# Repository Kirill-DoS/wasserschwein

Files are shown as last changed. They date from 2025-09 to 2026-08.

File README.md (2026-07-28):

# Wasserschwein — робот для физического «Арканоида»

Wasserschwein — это система, в которой камера сверху видит мяч и каретку
робота, а компьютер отправляет каретке команды движения. Raspberry Pi Pico
принимает эти команды по Bluetooth и управляет мотором. Цель — подвезти каретку
к месту, где мяч пересечёт её линию.

Это не обязательный проект с нейросетью: в обычной работе программа выделяет
мяч и метку робота по цвету. Это проще, быстрее и легче проверять. Нейросеть
YOLO оставлена только как отдельный эксперимент.

## Начните отсюда

Полное пошаговое руководство — от установки программ до проверки настоящего
робота — находится в [docs/PROJECT_GUIDE_RU.md](docs/PROJECT_GUIDE_RU.md).
Оно написано для человека, который не обязан знать ни машинное обучение, ни
фильтр Калмана.

Краткая безопасная последовательность для компьютерной части:

```bash
git clone https://github.com/Kirill-DoS/wasserschwein.git
cd wasserschwein
cp .env.example .env
python3 -m venv .venv
source .venv/bin/activate
python3 -m pip install -r requirements.txt
python3 -m unittest discover -s tests -v
```

Затем заполните `.env`, подключите камеру и Bluetooth-модуль, проведите
разметку поля и запустите:

```bash
python3 -m vision.main
```

## Самое важное о настройках

Все изменяемые настройки находятся в одном файле `.env` в корне репозитория:

- камера и Bluetooth;
- размеры поля и цветовые диапазоны;
- скорость и плавность движения каретки;
- параметры прошивки Pico, включая пины и таймер безопасности.

Файл `.env` не попадает в Git, потому что содержит настройки конкретного
стенда. В репозитории хранится только безопасный шаблон
[.env.example](.env.example). Не меняйте значения пинов и ESC, пока не
проверите схему и не прочитаете соответствующий раздел подробного руководства.

## Структура

```text
vision/        Компьютерное зрение, прогноз мяча и управление роботом
firmware/      Прошивка Raspberry Pi Pico и сборка файла .uf2
hardware/      Модели деталей и конструкторские материалы
tools/         Отдельные диагностические и учебные утилиты
tests/         Автоматические проверки без камеры и робота
docs/          Подробное руководство и правила поля
```

## Частые команды

| Задача | Команда из корня репозитория |
| --- | --- |
| Установить зависимости | `python3 -m pip install -r requirements.txt` |
| Запустить автоматические тесты | `python3 -m unittest discover -s tests -v` |
| Найти номер камеры | `python3 tools/camera_index.py` |
| Ручной стоп робота | `python3 -m vision.bluetooth_cli S` |
| Запустить игру | `python3 -m vision.main` |
| Собрать прошивку Pico | `make -C firmware all` |

## Безопасность

- Первые тесты выполняйте с поднятыми колёсами либо на минимальной мощности.
- Держите кнопку остановки и отключение питания в пределах руки.
- Закрытие программы, потеря мяча или метки робота отправляют команду `S`.
- Pico самостоятельно останавливает каретку, если новые команды не приходят
  дольше времени `PICO_COMMAND_TIMEOUT_MS` из `.env`.

Подробный порядок проверки и диагностики неисправностей — в
[руководстве](docs/PROJECT_GUIDE_RU.md).

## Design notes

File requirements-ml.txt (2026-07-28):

# Необязательные зависимости для экспериментов с YOLO, не нужны для управления роботом.
-r requirements.txt
ultralytics>=8.3
torch>=2.1
torchvision>=0.16
PyYAML>=6.0

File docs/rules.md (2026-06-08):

Полигон (см. рис. 1) представляет собой поле квадратной формы, ограниченное жестко
закрепленными бортами. Полигон имеет симметричную поперечную выпуклость в
центре. С противоположных сторон полигона установлены рейки для перемещения
роботов.
Характеристики полигона:
длина – 1500 мм;
ширина – 1500 мм;
высота бортов – не менее 100 мм;
толщина стенок – не менее 10 мм;
высота выпуклости – 35+/-10 мм;
форма продольного сечения выпуклости – равномерная криволинейная, с
плавным переходом к основанию полигона, опционально параболическая,
эллиптическая;
цвет полигона – белый;
Рейка представляет собой профиль квадратного сечения, жестко закрепленный на продольных бортах полигона

Характеристики рейки:
продольных бортах полигона.
Характеристики рейки:
размер сечения – квадрат со стороной 20 мм;
высота над полигоном – 100 мм;
расстояние до борта полигона – 100 мм;
материал – металл;
Характеристики мяча (опционально покрашенный мяч для гольфа):
цвет мяча – красный, оранжевый или розовый;
диаметр мяча – 43 мм;
масса мяча – 46

Веб-камеры:
размещение – на балку, смонтированную по продольной оси поля, на высоте
2000+/-200 мм;
направление обзора – вертикально вниз;
подключение – через USB порт к компьютеру участника.

4.2. Ход матча
Матч состоит из двух таймов.
Каждый тайм длится 3 минуты или пока разница в счете в тайме не достигнет 7 баллов.
В финальных матчах олимпийской системы длительность тайма составляет 5 минут.
Между таймами предусмотрен перерыв 3 минуты. По соглашению команд время
перерыва может быть уменьшено.
В начале тайма мяч вводится в игру от центра полигона в сторону определенную
жеребьевкой, параллельно боковым бортам. Каждый последующий ввод мяча
производится аналогично в направлении, противоположном направлению
предыдущего ввода мяча.
Гол засчитывается роботу, если мяч оказался полностью за рейкой противоположного
борта.
Потеря мяча происходит в случае, если мяч остановился так, что роботы не могут
произвести удар в сторону соперника.
Мяч вводится в игру после каждого гола, потери или нарушения.

5. Нарушения и дисквалификация
Нарушения, наказуемые присуждением 1 балла сопернику:
робот касается мяча дольше 2 секунд подряд
произошла потеря мяча на своей половине поля или мяч не выбит на сторону
соперника в течении 10 секунд после касания мяча роботом
Нарушения, наказуемые дисквалификацией робота в тайме:
участник коснулся полигона, робота или управляющий компьютер во время
матча без разрешения судьи
робот по техническим причинам (отказ моторов, разряд батареи, поломка
ударного механизма, переворот робота, отсутствие реакции робота на
перемещение мяча и пр.) или по усмотрению оператора не может
продолжать матч, в том числе, если не может перекинуть мяч на сторону
соперника
В случае дисквалификации робота соперника присуждаются дополнительные баллы в
количестве необходимом для досрочного завершения тайма с разницей 7 баллов в
пользу соперника

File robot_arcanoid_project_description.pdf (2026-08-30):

КЛУБ ТЕХНИЧЕСКОГО ТВОРЧЕСТВА «PINMODE»

## ОПИСАНИЕ ИННОВАЦИОННОГО ПРОЕКТА

«Разработка робота-арканоида для настольного тенниса»

Автор проекта:
Член клуба «PinMode»
Ломашко Данила Сергеевич

Минск, 2026

3. Введение (Постановка задачи) | 3
3.1. Актуальность исследования | 3
3.2. Цель и задачи проекта | 3
3.3. Гипотеза исследования | 3
4. Основная часть | 4
4.1. Архитектура и компонентная база аппаратного комплекса | 4
4.2. Конструктивное исполнение и кинематика передачи | 4
4.3. Выявленные инженерные проблемы и оптимизация конструкции | 5
5. Заключение | 6
5.1. Краткие выводы | 6
5.2. Практическая значимость | 6
5.3. Направления дальнейшего развития | 6
6. Список использованных источников | 7
7. Приложения | 7

### 2. ОГЛАВЛЕНИЕ

### 3. ВВЕДЕНИЕ (ПОСТАНОВКА ЗАДАЧИ)

### 3.1. Актуальность исследования

Проектирование специализированных робототехнических систем для динамических спортивных игр (в частности, настольного тенниса) требует решения жестких инженерных противоречий: обеспечения высокой скорости перемещения исполнительных органов при сохранении малого веса, высокой прочности и жесткости конструкции. Автоматизация процесса отбивания мяча сопряжена с необходимостью компенсации динамических нагрузок, возникающих при работе высокооборотистых бесколлекторных двигателей и резком изменении вектора движения. Разработка доступного, высокоскоростного робота-арканоида на базе современных микроконтроллерных платформ и аддитивных технологий является актуальной задачей в области прикладной мехатроники и робототехники.

### 3.2. Цель и задачи проекта

Цель работы: Разработка, сборка и отладка действующего прототипа робота-арканоида для настольного тенниса, способного позиционировать ударный механизм (пушер) и осуществлять отбивание мяча на высоких скоростях вращения импеллера без потери кинематической точности и устойчивости платформы.

Задачи проекта:

Спроектировать и изготовить несущую платформу робота на основе листовых полимерных материалов (ПВХ) и компонентов, изготовленных методом 3D-печати.
Разработать печатную плату системы управления и интегрировать аппаратный стек на базе микроконтроллера Raspberry Pi RP2040 Zero, мостовых драйверов TA6586, регуляторов скорости ESC и бесколлекторных моторов (BLDC).
Спроектировать и реализовать зубчато-ременную передачу с коэффициентом редукции 3:1 на базе профиля GT2 для привода пушера.
Исследовать и устранить динамические дефекты конструкции: опрокидывающий момент при разгоне/торможении и гироскопические прецессионные биения импеллера на частотах свыше 4000 об/мин.

### 3.3. Гипотеза исследования

Предполагается, что применение двухопорного двустороннего узла фиксации оси импеллера в сочетании с тефлоновыми (PTFE) опорами скольжения с низким коэффициентом трения позволит полностью устранить эффект «восьмерки» при оборотах BLDC-двигателя выше 4000 об/мин и стабилизировать пространственное положение робота без существенных механических потерь на трение.

### 4. ОСНОВНАЯ ЧАСТЬ

### 4.1. Архитектура и компонентная база аппаратного комплекса

Аппаратная схема робота-арканоида построена по модульному принципу с разделением силовых и управляющих цепей. В основе вычислительного ядра лежит микроконтроллер RP2040

1.

2.

3.

4.

Zero (двухядерный ARM Cortex-M0+, 133 МГц). Питание электроники осуществляется через импульсные понижающие DC-DC стабилизаторы, обеспечивающие помехозащищенность логической части от бросков напряжения силовых приводов.

Специально для данного проекта была спроектирована и изготовлена односторонняя печатная плата (PCB). На плате размещена обвязка центрального контроллера, включая интегральный двухканальный H-мостовой драйвер TA6586 для управления моторами позиционирования, светодиодные индикаторы статуса и пользовательские кнопки ввода команд.

Компонент | Характеристики / Модель | Назначение в системе
Микроконтроллер | RP2040 Zero (ARM Cortex-M0+) | Генерация ШИМ, обработка алгоритмов движения
Силовые приводы привода | 2х Коллекторных мотора Pololu 20 мм | Линейное перемещение платформы робота
Драйвер двигателей | TA6586 (DIP/SOP-8) | Управление коллекторными моторами Pololu
Привод пушера (отбивалки) | 2х BLDC 2200KV + 2х ESC 40A | Вращение импеллера ударного механизма
Плата управления | Односторонняя PCB собственного изготовления | Маршрутизация сигналов, обвязка МК и индикации

### 4.2. Конструктивное исполнение и кинематика передачи

Несущее шасси робота имеет габаритные размеры 250×120×5 мм и выполнено из высокопрочной ПВХ-плиты. Для защиты внутренних компонентов и жесткости конструкции по периметру установлены защитные боковые бортики. Передача крутящего момента от силовых бесколлекторных двигателей BLDC к валам пушера реализована посредством ременной передачи стандарта GT2. Кинематический расчет передачи выполнен исходя из коэффициента понижения скорости i = 3:1:

i = z₂ / z₁ = 3 / 1

где z₁ — количество зубьев ведущей шестерни на валу BLDC, z₂ — количество зубьев ведомой шестерни импеллера. Данное соотношение гарантирует передачу требуемого крутящего момента при сохранении высокого диапазона рабочих оборотов.

В процессе проектирования широко применялись аддитивные технологии (FDM-печать). На 3D-принтере износостойкими пластиками были изготовлены следующие оригинальные детали:

Корпусные держатели и кронштейны для тефлоновых элементов;
Мотомауты (крепления) для коллекторных и бесколлекторных двигателей;
Зубчатые шкивы и шестерни профиля GT2;
Переходные втулки для адаптации 3-мм валов BLDC-моторов; Стабилизационные кожухи для бесколлекторных двигателей.

•
•
•
•
•

### 4.3. Выявленные инженерные проблемы и оптимизация конструкции

В ходе натурных испытаний начальной версии прототипа были выявлены два существенных технических дефекта, влияющих на точность и надежность работы:

Проблема 1: Продольная неустойчивость платформы (заваливание вперед/назад). При резком изменении направления движения линейных приводов Pololu возникал опросный момент, заваливающий платформу.
Решение: В нижнюю часть шасси были интегрированы 4 опорных элемента из политетрафторэтилена (PTFE, тефлон), контактирующие с алюминиевым направляющим треком. За счет чрезвычайно низкого коэффициента трения тефлона по алюминию (μ ≈ 0.04) проблема заваливания платформы была полностью решена без увеличения паразитного механического сопротивления и потери мощности моторов.

Проблема 2: Динамический биение импеллера («восьмерка») на высоких оборотах. При росте частоты вращения BLDC-моторов свыше 4000 об/мин в импеллере (ударном блоке) возникали резонансные явления и гироскопический прецессионный момент. Поскольку первоначальная конструкция предусматривала консольное крепление вала импеллера только с верхней стороны, консоль испытывала изгибные деформации, что приводило к ходу детали «восьмеркой» и быстрому износу ремня GT2.

Решение (Текущий этап модернизации): В настоящее время осуществляется проектирование интегрированного силового силового узла (модульного моноблока). В новой ревизии вал импеллера фиксируется по схеме «двухопорная балка» — с оппозитным расположением подшипников сверху и снизу. Кроме того, в данный модуль заложены посадочные места для моторов и механизм точной регулировки натяжения ремня GT2 с помощью пазовых направляющих, что полностью ликвидирует несоосность и люфты.

### 5. ЗАКЛЮЧЕНИЕ

### 5.1. Краткие выводы

В ходе выполнения проекта был спроектирован, собран и проверен действующий прототип робота-арканоида для игры в настольный теннис. Натурные испытания подтвердили правильность выбранного кинематического соотношения ременной передачи (3:1) и
эффективность | применения | тефлоновых | слайдеров | для | стабилизации | корпуса.
Разрабатываемый модернизированный двухопорный узел крепления импеллера решает проблему пространственных вибраций на частотах более 4000 об/мин.

### 5.2. Практическая значимость

Разработая платформа демонстрирует высокий потенциал применения в качестве тренировочного оборудования для настольного тенниса, специализированных робототехнических аттракционов, а также в качестве учебного стенда в учреждениях образования для демонстрации
систем | управления | BLDC-двигателями, | динамической | балансировки | и | разработки
высокоскоростных приводов.

### 5.3. Направления дальнейшего развития

Завершение изготавливаемой конструкции двухопорного силового модуля импеллера и его интеграция в шасси;

•

Внедрение оптической системы технического зрения (на базе камеры) для автоматического отслеживания траектории теннисного мяча;
Разработка закрытого корпуса для улучшения аэродинамики и безопасности при работе на максимальных оборотах привода.

### 6. СПИСОК ИСПОЛЬЗОВАННЫХ ИСТОЧНИКОВ

Autodesk Inc. Autodesk Fusion 360: Integrated CAD/CAM/CAE Software [Электронный ресурс]. — 2026. — Режим доступа: https://www.autodesk.com/products/fusion-360
FreeCAD Community. FreeCAD: An open-source parametric 3D modeler [Электронный ресурс]. — 2026. — Режим доступа: https://www.freecad.org
Raspberry Pi Ltd. RP2040 Datasheet: High-performance microcontroller with flexible digital interfaces. — 2021. — 638 p.
Краузе М. Справочник по конструкционным пластмассам и фторопластам (PTFE/Тефлон). — Л.: Химия, 1988. — 224 с.

### 7. ПРИЛОЖЕНИЯ

Приложение А. Фотографические материалы действующего прототипа робота-арканоида (ракурсы: вид сверху, вид снизу, вид спереди).

•

•

1.

2.

3.

4.

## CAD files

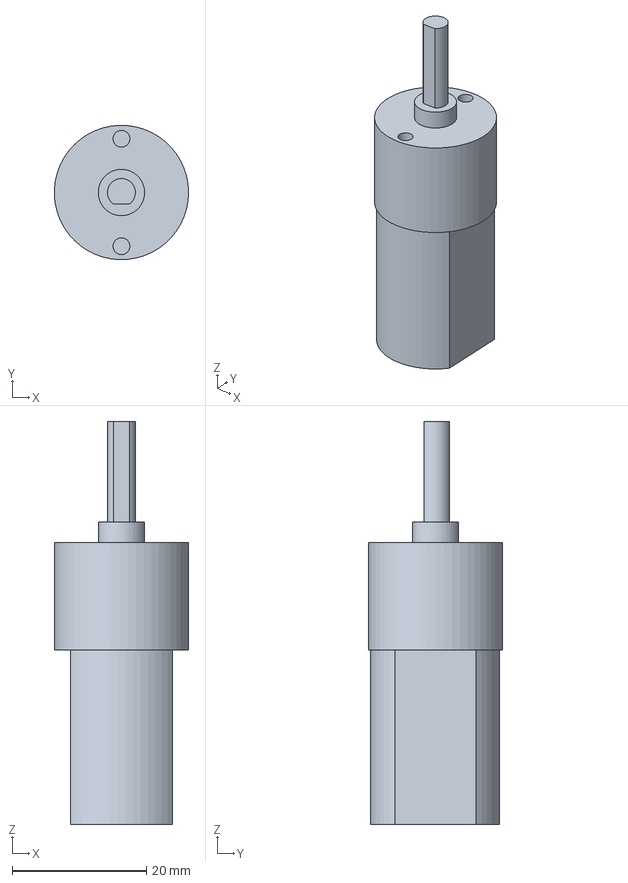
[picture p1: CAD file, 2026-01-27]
hardware/cad/3D_components/motor.FCStd
20.0 x 20.0 x 60.0 mm

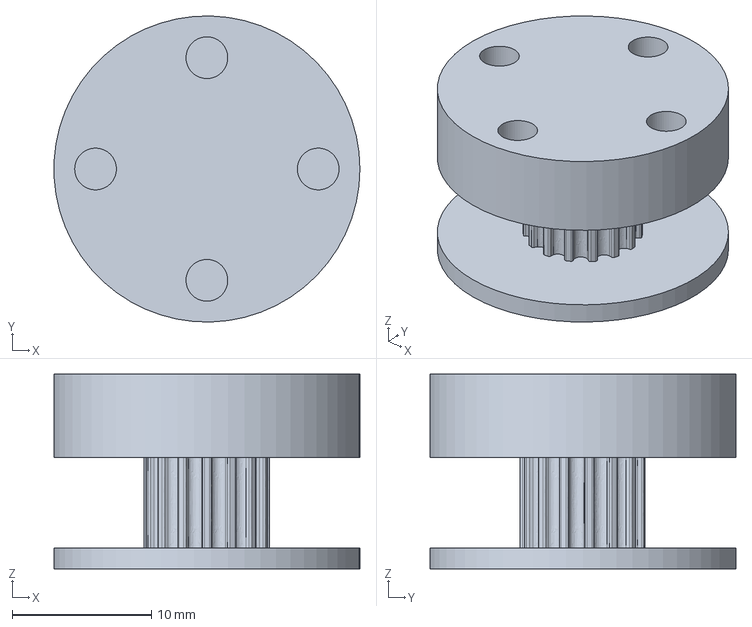
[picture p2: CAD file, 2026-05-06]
hardware/cad/NewPusherSys/BLCDGear.FCStd
22.0 x 22.0 x 14.0 mm

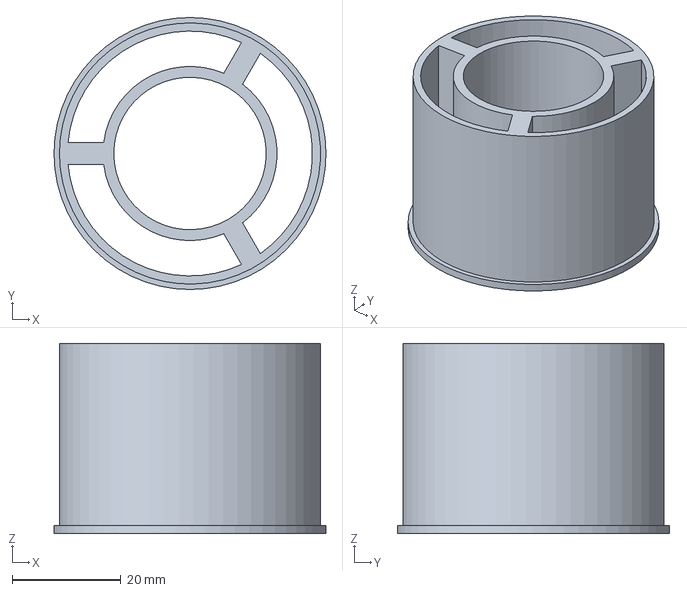
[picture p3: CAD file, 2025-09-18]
hardware/construction/Weel_pusher.FCStd
50.0 x 50.0 x 35.0 mm

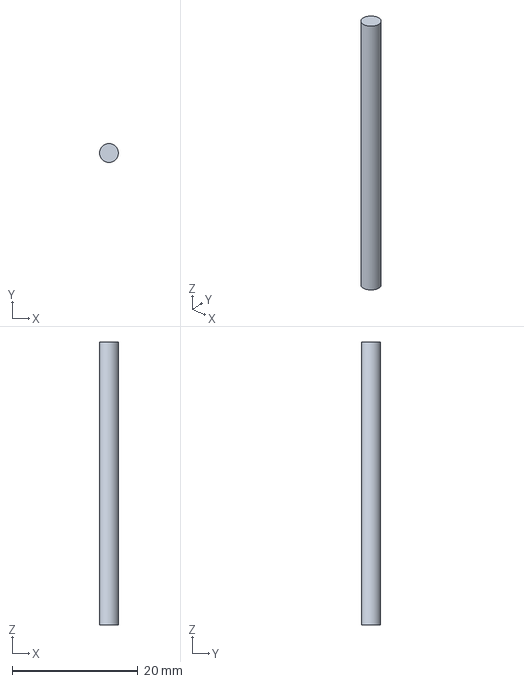
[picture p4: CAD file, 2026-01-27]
hardware/cad/3D_components/shaft.FCStd
3.00 x 3.00 x 45.0 mm

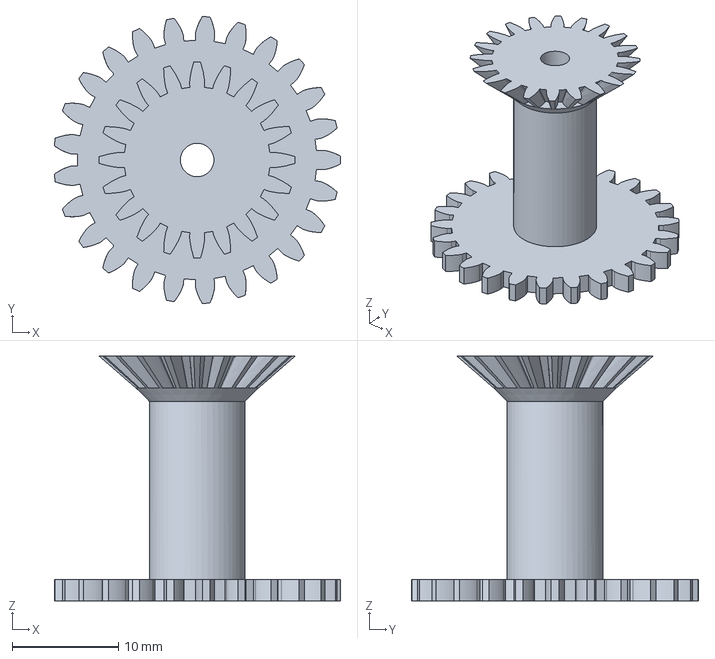
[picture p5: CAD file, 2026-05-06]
hardware/cad/involute_gear_1.FCStd
26.9 x 27.0 x 23.0 mm

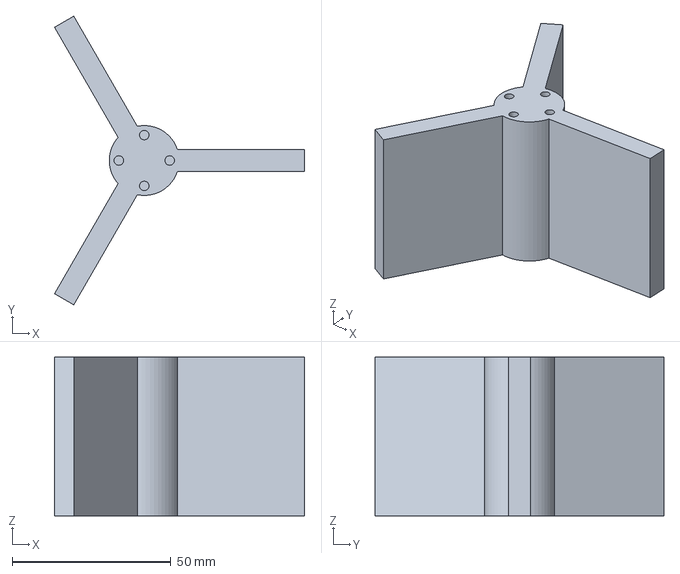
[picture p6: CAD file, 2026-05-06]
hardware/cad/NewPusherSys/pusher.FCStd
78.7 x 90.8 x 50.0 mm

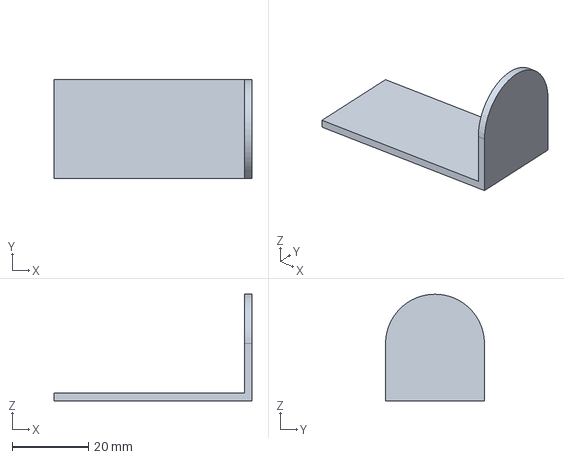
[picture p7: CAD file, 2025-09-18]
hardware/construction/arcanoid_cart.FCStd
52.0 x 26.0 x 28.0 mm

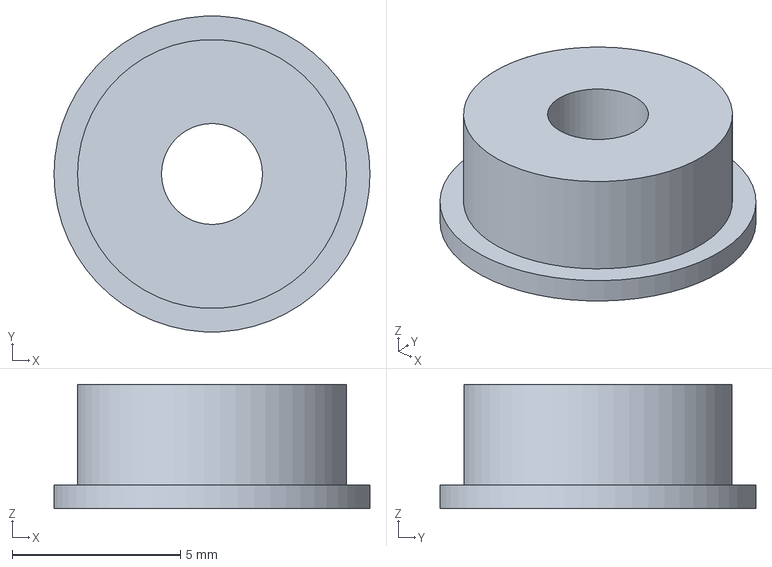
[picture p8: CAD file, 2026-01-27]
hardware/cad/3D_components/bearing.FCStd
9.40 x 9.39 x 3.70 mm

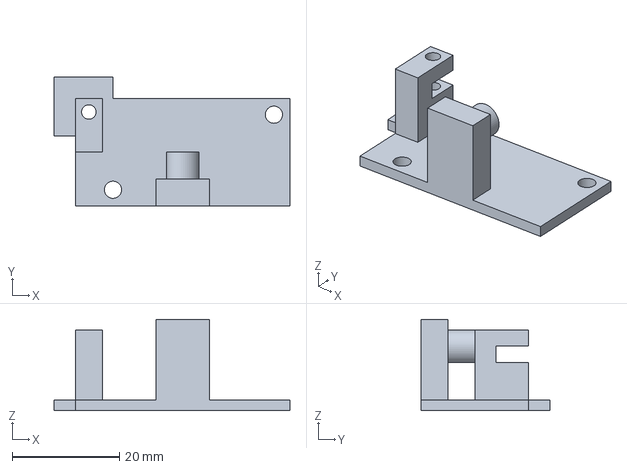
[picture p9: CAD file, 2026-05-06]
hardware/cad/NewPusherSys/BeltTightening.FCStd
44.0 x 24.0 x 17.0 mm

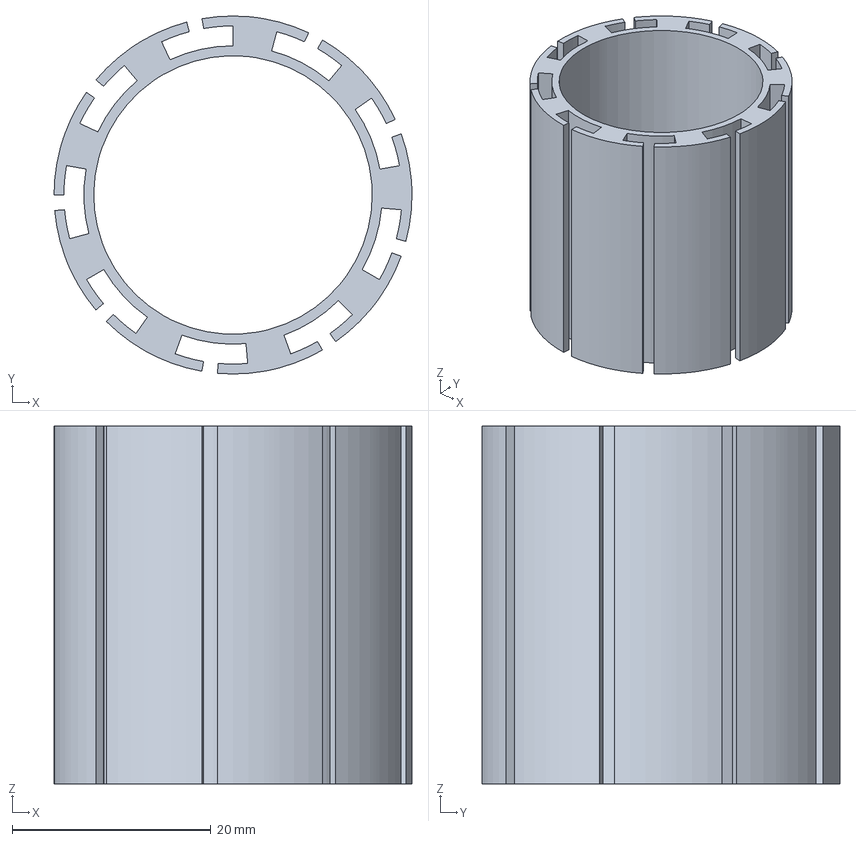
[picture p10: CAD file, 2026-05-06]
hardware/cad/weel_pusher_new.FCStd
36.0 x 36.0 x 36.0 mm

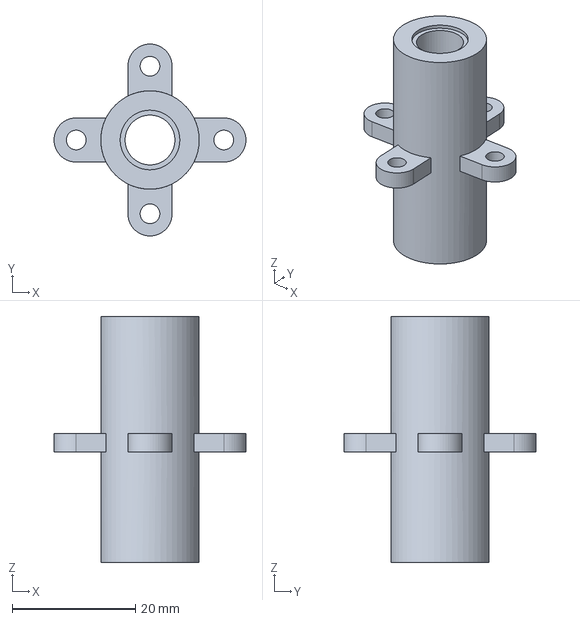
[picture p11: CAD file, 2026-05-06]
hardware/cad/NewPusherSys/Sleeve.FCStd
31.2 x 31.2 x 40.0 mm

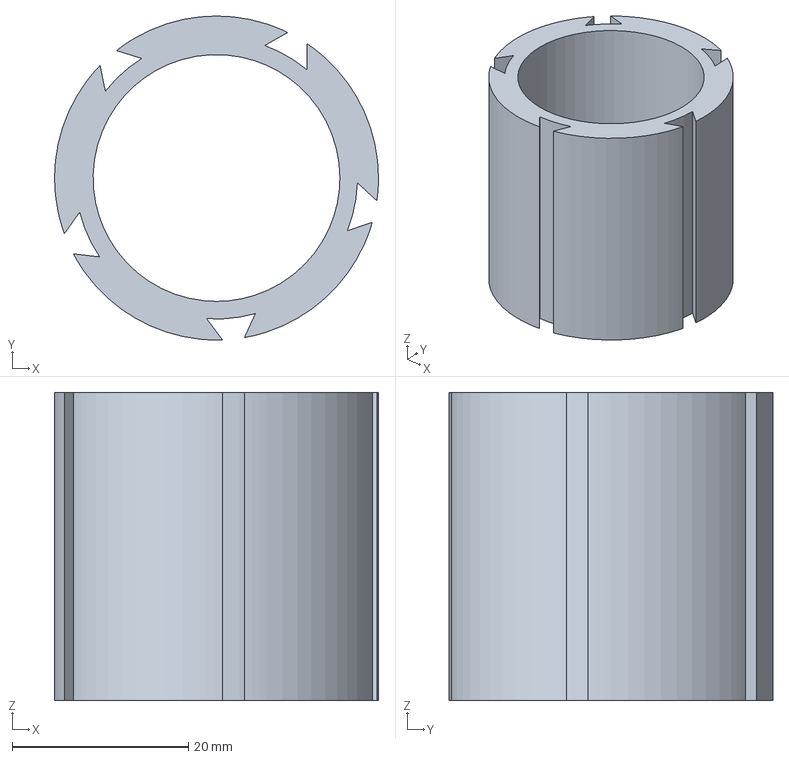
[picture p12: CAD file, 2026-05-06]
hardware/cad/weel_pusher.FCStd
36.8 x 36.8 x 35.0 mm

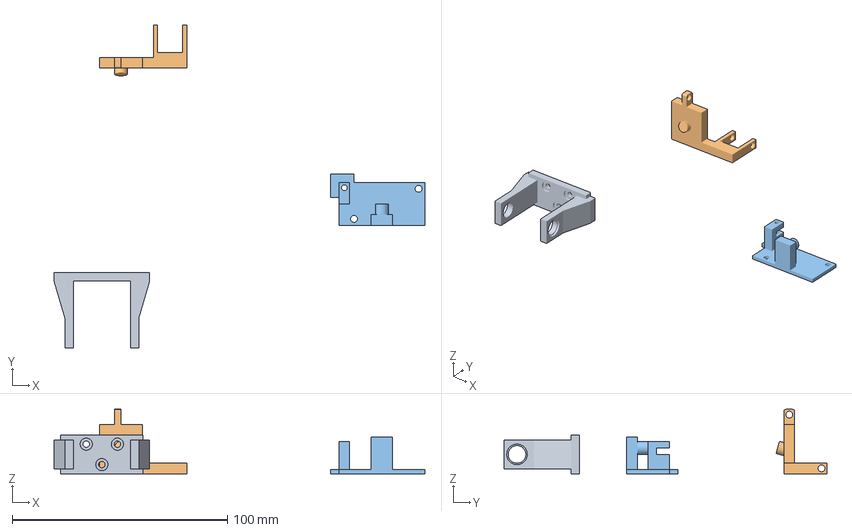
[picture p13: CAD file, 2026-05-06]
hardware/cad/NewPusherSys/weel_kiper.3mf
172.5 x 150.1 x 30.0 mm

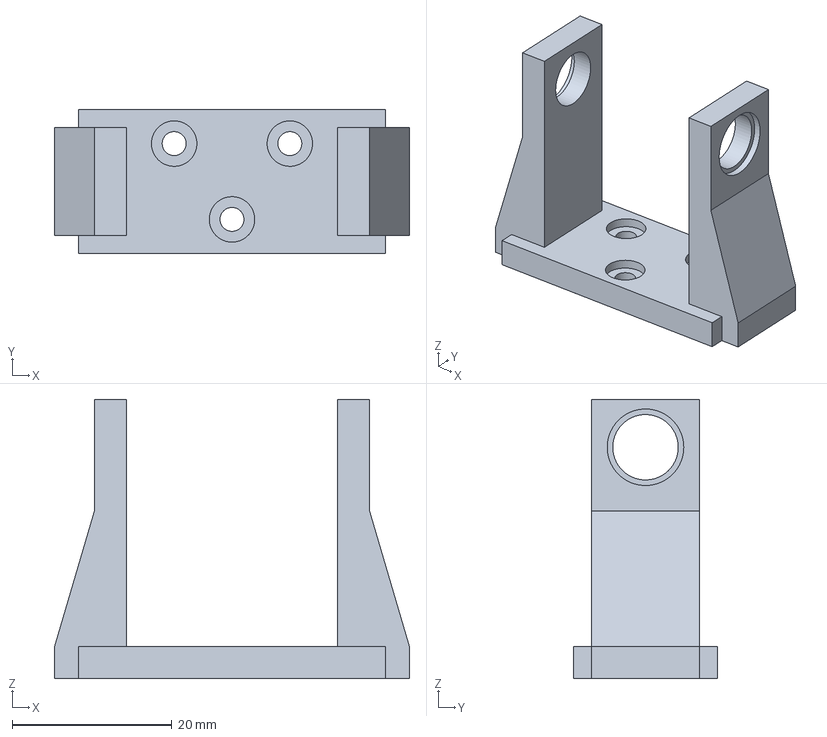
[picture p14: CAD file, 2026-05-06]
hardware/cad/weel_kiper.FCStd
44.5 x 18.0 x 35.0 mm

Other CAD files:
hardware/cad/assembly_pusher.FCStd
hardware/cad/assembly_robot.FCStd
hardware/cad/back_form_pusher.FCStd
hardware/cad/NewPusherSys/ArmTightening.FCStd
hardware/cad/BLCD_kipper.FCStd
hardware/cad/NewPusherSys/ArmTightening.3mf
hardware/cad/NewPusherSys/BLCDGear.3mf
hardware/cad/NewPusherSys/BeltTightening.3mf
hardware/cad/NewPusherSys/BigGear.3mf
hardware/cad/NewPusherSys/BigGear.FCStd
hardware/cad/NewPusherSys/CurtainDrive.FCStd
hardware/cad/NewPusherSys/Sleeve.3mf
hardware/cad/NewPusherSys/WeelTightening.3mf
hardware/cad/NewPusherSys/WeelTightening.FCStd
hardware/cad/NewPusherSys/pusher.3mf
hardware/cad/arcanoid1.3mf.FCStd
hardware/cad/arcanoid_new.3mf
hardware/cad/arcanoid_new.FCStd
hardware/cad/bevel_gear_1.FCStd
hardware/cad/bevel_gear_3.FCStd
hardware/cad/board_stands.3mf
hardware/cad/brain_kipper.FCStd
hardware/cad/curtainDrive.FCStd
hardware/cad/form_pusher.FCStd
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

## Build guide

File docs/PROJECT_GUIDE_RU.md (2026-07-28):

# Полное понятное руководство по Wasserschwein

> Это руководство рассчитано на первый запуск. Вам не нужно заранее знать
> машинное обучение, OpenCV, фильтр Калмана или Raspberry Pi Pico. Все команды
> ниже выполняются из корневой папки проекта — той, где лежит файл `README.md`.

## Содержание

1. [Что делает проект](#1-что-делает-проект)
2. [Как устроена система](#2-как-устроена-система)
3. [Словарь простыми словами](#3-словарь-простыми-словами)
4. [Безопасность до первого включения](#4-безопасность-до-первого-включения)
5. [Что понадобится](#5-что-понадобится)
6. [Структура папок](#6-структура-папок)
7. [Первичная установка на компьютере](#7-первичная-установка-на-компьютере)
8. [Единый файл настроек `.env`](#8-единый-файл-настроек-env)
9. [Сборка и прошивка Raspberry Pi Pico](#9-сборка-и-прошивка-raspberry-pi-pico)
10. [Подключение Bluetooth](#10-подключение-bluetooth)
11. [Проверка без движения робота](#11-проверка-без-движения-робота)
12. [Калибровка камеры и поля](#12-калибровка-камеры-и-поля)
13. [Полный запуск игры](#13-полный-запуск-игры)
14. [Автоматические тесты](#14-автоматические-тесты)
15. [Проверки с настоящим железом](#15-проверки-с-настоящим-железом)
16. [Как настраивать поведение робота](#16-как-настраивать-поведение-робота)
17. [Что было исправлено и почему](#17-что-было-исправлено-и-почему)
18. [Дополнительные утилиты и YOLO](#18-дополнительные-утилиты-и-yolo)
19. [Типичные неполадки](#19-типичные-неполадки)
20. [Как обновлять проект](#20-как-обновлять-проект)

## 1. Что делает проект

Это робот для физической версии игры «Арканоид». Мяч движется по реальному
полю, а каретка робота ездит по своей линии. Камера сверху снимает поле,
компьютер понимает, где сейчас мяч, примерно рассчитывает его путь и отправляет
каретке команду: ехать влево, вправо или остановиться.

Обычная работа не требует нейросети. Программа ищет мяч и метку робота по
выбранному цвету. Это хорошо подходит для контролируемого стенда: цвет мяча,
метки и поля можно сделать различимыми. В папке `tools/ml/` есть отдельные
эксперименты с YOLO, но они не нужны, чтобы робот начал ездить.

## 2. Как устроена система

```mermaid
flowchart LR
    A["Камера над полем"] --> B["Python: поиск цвета"]
    B --> C["Прогноз точки встречи"]
    B --> D["Поиск метки каретки"]
    C --> E["Регулятор движения"]
    D --> E
    E --> F["Bluetooth HC-06"]
    F --> G["Raspberry Pi Pico"]
    G --> H["Драйвер и мотор каретки"]
```

Роли частей простые:

- **Камера** даёт новые кадры поля несколько раз в секунду.
- **Python-программа** на компьютере находит мяч и робота, переводит их
  координаты в миллиметры поля и решает, куда двигаться.
- **Bluetooth HC-06** передаёт короткие текстовые команды.
- **Raspberry Pi Pico** выполняет команды и управляет выходами моторов.
- **Watchdog (сторожевой таймер)** в Pico останавливает привод, если компьютер
  завис, выключился или потерял связь.

## 3. Словарь простыми словами

| Слово | Что это означает без сложной математики |
| --- | --- |
| Кадр | Одна фотография от камеры. Видео — это много таких фотографий подряд. |
| OpenCV | Библиотека Python, которая умеет открывать камеру, работать с цветом и рисовать отладку. |
| HSV | Удобный способ хранить цвет: оттенок, насыщенность и яркость. По нему легче отличить цветной мяч от фона, чем по обычным RGB-числам. |
| HSV-маска | Чёрно-белая картинка: белое — пиксели подходящего цвета, чёрное — всё остальное. |
| Контур | Граница найденного белого пятна на HSV-маске. По ней программа отличает круглый мяч от случайного блика. |
| Гомография | «Карта-переводчик» между наклонённой картинкой камеры и ровной схемой поля сверху. Благодаря ей программа понимает расстояния на поле, а не только номера пикселей. |
| Фильтр Калмана | Математическое сглаживание. Он соединяет несколько наблюдений мяча, чтобы единичный дрожащий кадр не заставил робота резко дёрнуться. Это не нейросеть. |
| Прогноз | Приближённый расчёт того, где мяч встретит линию каретки. Это полезная оценка, а не гарантированное предсказание будущего. |
| PWM / ШИМ | Число, задающее долю мощности мотора. В этом проекте для движения каретки — от 0 до 255. |
| ESC | Электронный контроллер бесколлекторного двигателя толкателя. Он получает импульсы длительностью примерно 1000–2000 микросекунд. |
| Pico SDK | Набор инструментов и библиотек, с которыми собирается программа для Raspberry Pi Pico. |
| Прошивка | Программа внутри Pico. После сборки она получается в файле `.uf2`. |
| `.env` | Обычный текстовый файл с настройками в виде `ИМЯ=ЗНАЧЕНИЕ`. В нём нет программного кода. |
| Виртуальное окружение (`.venv`) | Изолированная папка Python-зависимостей для одного проекта. Её можно удалить и создать заново. |

## 4. Безопасность до первого включения

Движущийся робот — это не только программа. Ошибка в проводах, направлении
мотора или настройке мощности может заставить каретку резко поехать. Поэтому:

1. Сначала убедитесь, что питание можно быстро отключить одной рукой.
2. Первую проверку выполните без мяча и с поднятыми ведущими колёсами либо на
   механически безопасной малой мощности.
3. Перед подачей питания отправьте ручную команду стопа `S`.
4. Не меняйте номера пинов Pico и значения ESC «наугад».
5. Не оставляйте робот работающим без оператора.
6. Если что-то ведёт себя неожиданно — нажмите кнопку остановки, отключите
   питание и только потом разбирайтесь с кодом.

В программе есть две страховки:

- компьютер посылает `S`, если потерян мяч, метка робота, камера или программа
  завершается;
- Pico прекращает движение, если не получает корректную команду дольше
  `PICO_COMMAND_TIMEOUT_MS` миллисекунд из `.env`.

## 5. Что понадобится

### Компьютер

- Linux-компьютер (команды Bluetooth ниже ориентированы на Linux);
- Python 3.10 или новее;
- доступ в интернет только для первой установки Python-пакетов;
- USB-камера, которую видит система;
- Bluetooth-модуль HC-06, связанный с Pico.

### Робот

- Raspberry Pi Pico;
- собранная механика, моторный драйвер и питание;
- подключённые по вашей схеме моторы, кнопка, светодиод и, если используется,
  ESC толкателя;
- возможность перевести Pico в режим загрузчика: удерживать `BOOTSEL` при
  подключении USB.

### Перед началом проверьте

- камера смотрит на поле сверху и её крепление не шатается;
- мяч имеет хорошо заметный цвет;
- метка каретки имеет другой хорошо заметный цвет;
- на поле нет цветных предметов такого же цвета, как мяч или метка;
- Pico отключён от опасной нагрузки на время первой прошивки.

## 6. Структура папок

```text
.
├── .env.example             Шаблон всех настроек
├── vision/                  Основная программа компьютерного зрения
│   ├── main.py              Полный запуск камеры и робота
│   ├── bluetooth_cli.py     Одна ручная Bluetooth-команда
│   ├── config.py            Чтение и запись настроек .env
│   └── calibration/         Результаты разметки поля
├── firmware/                Исходники и сборка Raspberry Pi Pico
│   └── src/                 Код на языке C
├── hardware/
│   ├── cad/                 3D-модели деталей и сборок
│   └── construction/        Конструкторские материалы
├── tools/
│   ├── camera_index.py      Поиск номера камеры
│   ├── hsv_tuner.py         Подбор HSV-цвета вне полной игры
│   ├── check_gpu.py         Диагностика GPU для экспериментов ML
│   └── ml/                  Необязательные сценарии подготовки YOLO
├── tests/                   Автоматические тесты без железа
└── docs/                    Эта документация и правила поля
```

Папки `.venv`, `build`, временные файлы Python и ваш `.env` специально не
хранятся в Git. Они создаются на конкретном компьютере и не должны засорять
историю проекта.

## 7. Первичная установка на компьютере

### 7.1 Получите исходный код

Если проект ещё не скачан:

```bash
git clone https://github.com/Kirill-DoS/wasserschwein.git
cd wasserschwein
```

Если он уже есть, просто откройте терминал в его корневой папке. Проверить это
можно так:

```bash
ls README.md .env.example requirements.txt
```

Команда должна показать все три файла.

### 7.2 Создайте свои настройки

```bash
cp .env.example .env
```

`.env.example` остаётся нетронутым: это общий шаблон. `.env` — ваша локальная
копия с параметрами именно вашего робота. Откройте `.env` в любом текстовом
редакторе и сначала проверьте хотя бы `CAMERA_ID`, `BT_PORT` и `BT_HC06_MAC`.

### 7.3 Создайте окружение Python и установите библиотеки

```bash
python3 -m venv .venv
source .venv/bin/activate
python3 -m pip install --upgrade pip
python3 -m pip install -r requirements.txt
```

Что произошло:

- первая команда создала папку `.venv`;
- вторая включила её только для текущего окна терминала;
- третья обновила установщик пакетов;
- четвёртая поставила `numpy`, `opencv-python` и `pyserial`.

Когда окружение включено, начало строки терминала обычно содержит `(.venv)`.
После закрытия терминала включите окружение снова:

```bash
cd /путь/к/wasserschwein
source .venv/bin/activate
```

Чтобы выйти из него, выполните `deactivate`. Удалять `.venv` безопасно: при
необходимости создайте её повторно командами выше.

### 7.4 Быстрая проверка установки

```bash
python3 -m unittest discover -s tests -v
python3 tools/camera_index.py
```

Первая команда должна закончиться словом `OK`. Вторая переберёт доступные номера
камер. Если нужная камера находится, запомните её номер и запишите в
`CAMERA_ID` файла `.env`.

## 8. Единый файл настроек `.env`

### Главное правило

Все значения, которые обычно надо подстраивать под конкретный стенд, находятся
в одном месте — в корневом `.env`. Не ищите их в `vision/*.py` или в
`firmware/src/constants.h`.

Python читает `.env` при старте. При сборке Pico специальный скрипт создаёт
временный заголовок C в папке `firmware/build/`; исходники прошивки не
переписываются. Поэтому изменение настройки Pico вступает в силу только после
новой сборки и прошивки `.uf2`.

Формат строки простой:

```text
ИМЯ_НАСТРОЙКИ=значение
```

Не ставьте пробелы вокруг `=`. Строки, начинающиеся с `#`, — комментарии и ни
на что не влияют.

### 8.1 Камера и Bluetooth

| Настройка | Простое назначение | Когда менять |
| --- | --- | --- |
| `CAMERA_ID` | Номер камеры в Linux: обычно `0`, иногда `1`. | Камера не открывается или подключено несколько камер. |
| `CAMERA_WIDTH`, `CAMERA_HEIGHT` | Разрешение кадра. | Только если камера не поддерживает текущее разрешение. После изменения обязательно повторить разметку. |
| `CAMERA_FPS` | Желаемое число кадров в секунду. | Если камера реально умеет другое значение. |
| `BT_PORT` | Файл Bluetooth-порта, обычно `/dev/rfcomm0`. | Если вы подключили HC-06 к другому номеру. |
| `BT_BAUDRATE` | Скорость обмена компьютера с HC-06. | Только если она совпадающе изменена в модуле и Pico. |
| `BT_HC06_MAC` | Адрес конкретного HC-06. | На другом Bluetooth-модуле. |
| `COMMAND_RESEND_INTERVAL_S` | Как часто компьютер повторяет текущую команду. | Обычно не менять. Значение должно быть меньше тайм-аута Pico. |

### 8.2 Поле и поиск объектов

| Настройка | Простое назначение | Практический совет |
| --- | --- | --- |
| `FIELD_WIDTH_MM`, `FIELD_HEIGHT_MM` | Настоящие размеры игрового поля в миллиметрах. | Измерьте рулеткой. Неверные значения меняют масштаб скорости и расстояний. |
| `VIRTUAL_FIELD_WIDTH`, `VIRTUAL_FIELD_HEIGHT` | Размер внутренней плоской карты программы. | Не меняйте без необходимости; это не реальные миллиметры. |
| `BALL_HSV_LOWER`, `BALL_HSV_UPPER` | Нижняя и верхняя граница цвета мяча: три числа через запятую. | Обычно сохраняются автоматически после калибровки цвета. |
| `ROBOT_HSV_LOWER`, `ROBOT_HSV_UPPER` | Граница цвета метки каретки. | Подберите, если программа не видит робота или видит посторонний предмет. |
| `BALL_TIMEOUT_S` | Сколько секунд программа ещё терпит отсутствие мяча. | Меньше — безопаснее, но возможны лишние остановки. Начните с `0.25`. |
| `BALL_MIN_RADIUS_PX`, `BALL_MAX_RADIUS_PX` | Допустимый радиус мяча на кадре в пикселях. | Измените, если камера поднята/опущена и мяч стал заметно больше/меньше. |
| `BALL_MIN_AREA_PX` | Минимальная площадь пятна мяча. | Увеличьте, если блики ошибочно считаются мячом. |
| `BALL_MIN_CIRCULARITY` | Насколько пятно должно быть похожим на круг. | Увеличьте, если программа ловит длинные цветные полосы. |
| `ROBOT_MIN_RADIUS_PX`, `ROBOT_MAX_RADIUS_PX` | Допустимый размер цветной метки каретки. | Подстраивайте аналогично мячу. |
| `ROBOT_TRACKER_FILTER_LENGTH` | Сколько последних положений метки сглаживать. | Больше — плавнее, но медленнее реакция. |

### 8.3 Прогноз мяча

Эти параметры не являются «магическим ИИ». Это ручные числа приближённой
модели движения:

| Настройка | Что делает |
| --- | --- |
| `BALL_CURVATURE_K` | Добавляет небольшой изгиб траектории в модели. Если поле ровное и мяч катится прямо, можно уменьшать к нулю. |
| `BALL_FRICTION` | Насколько быстро модель уменьшает скорость мяча из-за трения. |
| `BALL_RESTITUTION` | Какая доля скорости остаётся после удара о боковую стену. `1` — очень упругий удар, меньше `1` — мяч замедляется. |
| `BALL_MAX_SIM_STEPS` | Максимальная длина расчёта будущей траектории. Обычно не требует изменения. |
| `BALL_HISTORY_LENGTH` | Сколько точек прошлого пути рисовать для отладки. На управление почти не влияет. |
| `BALL_MIN_PREDICTION_SPEED_MM_S` | Скорость, ниже которой мяч считается почти стоящим. |
| `BALL_STOP_SPEED_MM_S` | Скорость, ниже которой расчёт будущего пути прекращается. |

Если робот систематически едет не туда, сначала проверьте разметку поля и
цветовую маску. Только затем осторожно настраивайте эти числа по одному.

### 8.4 Движение каретки

| Настройка | Что делает | Как менять |
| --- | --- | --- |
| `CONTROLLER_MAX_SPEED_MM_S` | Самая большая желаемая скорость каретки в миллиметрах в секунду. | Начните с меньшего значения и повышайте только после безопасных тестов. |
| `CONTROLLER_MAX_ACC_MM_S2` | Насколько быстро каретка имеет право разгоняться и тормозить. | Меньше — мягче движение; больше — резче реакция. |
| `CONTROLLER_DEADBAND_MM` | Зона около цели, в которой робот не пытается «ловить каждый миллиметр». | Увеличьте, если каретка дрожит около цели. |
| `MOTOR_MAX_PWM` | Верхняя граница мощности мотора, обычно не больше `255`. | Временно уменьшите для первых испытаний. |

### 8.5 Pico, пины и таймер безопасности

Настройки с префиксом `PICO_` нужны при сборке прошивки. Они не меняют
работающий Pico сами по себе: после изменения выполните сборку, скопируйте новый
`.uf2` и перезагрузите контроллер.

| Группа | Настройки | Что это |
| --- | --- | --- |
| Двигатель каретки | `PICO_MOTOR_WRAP`, `PICO_MOTOR_FREQ_HZ` | Технические параметры PWM. Обычно оставьте как есть. |
| ESC толкателя | `PICO_SERVO_WRAP`, `PICO_SERVO_DIVIDER`, `PICO_ESC_*` | Диапазоны и рабочие импульсы ESC. Меняйте только по документации именно вашего ESC. |
| Безопасность | `PICO_COMMAND_TIMEOUT_MS`, `PICO_CALIBRATE_ESC_ON_BOOT` | Таймер остановки и флаг калибровки ESC при запуске. Калибровка по умолчанию выключена (`0`). |
| Связь | `PICO_UART_BAUDRATE`, `PICO_PIN_TX`, `PICO_PIN_RX` | Скорость UART и пины, к которым подключён HC-06. Скорость должна совпадать с `BT_BAUDRATE`. |
| Остальная плата | `PICO_PIN_LED`, `PICO_PIN_BUTTON`, `PICO_PIN_SERVO1`, `PICO_PIN_SERVO2`, `PICO_PIN_MOTOR_LEFT`, `PICO_PIN_MOTOR_RIGHT`, `PICO_PIN_BATTERY` | Номера физических выводов Pico. Менять только после проверки схемы. |

> `PICO_CALIBRATE_ESC_ON_BOOT=1` включает процедуру калибровки ESC при каждом
> старте. Это может привести к неожиданным импульсам на механизме. Для обычной
> игры оставляйте `0`.

### 8.6 Необязательные настройки YOLO

Обычная игра эти значения не использует. Они нужны только сценариям из
`tools/ml/`, если вы решите экспериментировать с нейросетью.

| Настройка | Что делает |
| --- | --- |
| `YOLO_MODEL` | Имя базовой модели, которую скачает библиотека YOLO. |
| `YOLO_CONFIDENCE` | Насколько уверенным должно быть распознавание при черновой авторазметке. Больше — меньше ложных находок, но больше пропусков. |
| `YOLO_DEFAULT_EPOCHS` | Сколько проходов по датасету делает обучение по умолчанию. |
| `YOLO_IMAGE_SIZE`, `YOLO_BATCH_SIZE` | Размер изображения и число изображений, обрабатываемых одновременно. Большее значение требует больше памяти GPU. |
| `YOLO_FREEZE_LAYERS`, `YOLO_PATIENCE`, `YOLO_WORKERS` | Технические параметры обучения. Без опыта оставьте исходные значения. |
| `YOLO_VALIDATION_FRACTION`, `YOLO_RANDOM_SEED` | Доля картинок для проверки и фиксированное «зерно» случайности, чтобы разделение можно было повторить. |

### 8.7 Что появляется после калибровки

В `vision/calibration/` лежат файлы геометрии. Они описывают, как камера видит
конкретное поле. Файл `geometry.json` создаётся автоматически и не хранится в
Git, поскольку зависит от камеры и её положения. Если камера сдвинулась,
изменили высоту, зум или разрешение — удалите этот файл и проведите разметку
заново:

```bash
rm vision/calibration/geometry.json
```

Удалять `.npy` из поставки обычно не нужно. Разметчик перезапишет их при новой
калибровке.

## 9. Сборка и прошивка Raspberry Pi Pico

### 9.1 Установите инструменты

Нужны компилятор для ARM, CMake, Make, Python и Pico SDK. На Debian/Ubuntu
обычно достаточно:

```bash
sudo apt update
sudo apt install build-essential cmake git gcc-arm-none-eabi libnewlib-arm-none-eabi python3
git clone https://github.com/raspberrypi/pico-sdk.git "$HOME/pico/pico-sdk"
cd "$HOME/pico/pico-sdk"
git submodule update --init
```

На другой системе установите аналогичные пакеты привычным менеджером пакетов.
Pico SDK можно разместить в другом месте — важно только правильно указать путь
в следующем шаге.

### 9.2 Соберите файл прошивки

Вернитесь в папку проекта. В `.env` укажите реальный путь к SDK и папку, куда
Linux подключает Pico в режиме BOOTSEL. Например:

```text
PICO_SDK_PATH=/home/ivan/pico/pico-sdk
PICO_MOUNT_POINT=/run/media/ivan/RPI-RP2
```

Затем убедитесь, что `.env` создан, и соберите прошивку:

```bash
cd /путь/к/wasserschwein
test -f .env && echo ".env найден"
make -C firmware all
```

Во время сборки CMake читает `.env`, создаёт временный файл
`firmware/build/generated/generated_env.h`, а затем компилирует прошивку. Это
нормально: временный заголовок не нужно редактировать руками.

Если всё прошло успешно, итоговый файл будет здесь:

```text
firmware/build/arcanoid_main_file.uf2
```

Для повторной сборки после изменения исходников или `.env`:

```bash
make -C firmware fast
```

Сборка видит изменение `.env` и заново создаёт временный заголовок настроек
автоматически. Всё равно убедитесь, что потом загрузили новый `.uf2` именно в
Pico: пересборка сама по себе не меняет уже прошитый контроллер.

Если CMake «запомнил» старый путь к SDK или вы сильно меняли настройки сборки,
сделайте чистую сборку:

```bash
make -C firmware clean
make -C firmware all
```

### 9.3 Загрузите `.uf2` в Pico

1. Отключите Pico от USB.
2. Зажмите кнопку `BOOTSEL` на Pico.
3. Не отпуская её, подключите USB к компьютеру.
4. В системе появится диск `RPI-RP2`.
5. Скопируйте на него файл `.uf2`.

Например, если диск смонтирован как `/run/media/имя/RPI-RP2`:

```bash
cp firmware/build/arcanoid_main_file.uf2 /run/media/имя/RPI-RP2/
```

После копирования Pico сам перезагрузится и запустит новую прошивку. Цель
`make -C firmware deploy` делает такую копию автоматически только если
`PICO_MOUNT_POINT` в `.env` соответствует вашей системе.

### 9.4 Важное правило после изменения `.env`

- Изменили `CAMERA_*`, HSV, размеры поля или параметры каретки — перезапустите
  Python-программу.
- Изменили любой `PICO_*` или `MOTOR_MAX_PWM` — пересоберите и заново прошейте
  Pico.
- Изменили `BT_BAUDRATE` или `PICO_UART_BAUDRATE` — значения должны быть
  одинаковыми, иначе связь не заработает.

## 10. Подключение Bluetooth

Этот раздел рассчитан на HC-06, подключённый к UART Pico. Сначала узнайте MAC
адрес модуля; в Linux это можно сделать через настройки Bluetooth или командой
`bluetoothctl devices`. Запишите адрес в `BT_HC06_MAC` файла `.env`.

Создайте последовательный Bluetooth-порт:

```bash
sudo rfcomm connect 0 "$(grep '^BT_HC06_MAC=' .env | cut -d= -f2)" 1
```

После успешного подключения должен существовать файл `/dev/rfcomm0`. Если у вас
другой номер, измените и команду, и `BT_PORT` в `.env`.

Проверка:

```bash
ls -l /dev/rfcomm0
```

Окно с `rfcomm connect` обычно оставляют открытым на время игры. При отключении
связи программа Pico всё равно должна остановить каретку по таймеру безопасности.

## 11. Проверка без движения робота

Не начинайте с автоматического запуска. Сначала проверим отдельные части.

### 11.1 Камера

```bash
source .venv/bin/activate
python3 tools/camera_index.py
```

Если скрипт нашёл камеру с номером `1`, измените строку в `.env`:

```text
CAMERA_ID=1
```

### 11.2 Настройки Pico без компиляции

Эта команда проверяет, что генератор может прочитать `.env` и создать C-заголовок:

```bash
python3 tools/generate_firmware_env.py --env .env --output /tmp/generated_env.h
```

Успешный запуск ничего не печатает и создаёт `/tmp/generated_env.h`. Ошибка с
названием настройки означает: добавьте эту строку в `.env`, сверившись с
`.env.example`.

### 11.3 Ручная команда Bluetooth

Сначала убедитесь, что колёса свободны от пола или мощность ограничена. Затем:

```bash
python3 -m vision.bluetooth_cli S
python3 -m vision.bluetooth_cli F 30
python3 -m vision.bluetooth_cli S
```

Команды означают:

| Команда | Значение |
| --- | --- |
| `S` | Немедленно остановить каретку и ESC. |
| `F 0` … `F 255` | Движение в одном направлении с указанной мощностью. |
| `B 0` … `B 255` | Движение в обратном направлении. |
| `L 1000` … `L 2000` | Импульс левому ESC толкателя. |
| `R 1000` … `R 2000` | Импульс правому ESC толкателя. |

Если направление оказалось обратным ожидаемому, остановите робот. Не
компенсируйте это случайной заменой букв во многих файлах: сначала проверьте
проводку и логику направления в `vision/main.py`, затем внесите одно осознанное
изменение и перепроверьте команды `F` и `B`.

## 12. Калибровка камеры и поля

Калибровка отвечает на вопрос: «какая точка на картинке соответствует какой
точке на настоящем поле?». Без неё программа не может безопасно перевести
пиксели в миллиметры.

### 12.1 Когда её нужно делать

Сделайте новую разметку, если:

- камеру сдвинули, повернули, подняли или опустили;
- изменили разрешение `CAMERA_WIDTH` / `CAMERA_HEIGHT`;
- поменяли объектив или зум;
- заменили поле или заметно передвинули стены/рейку.

### 12.2 Запуск разметки

Если калибровки нет, `vision.main` сам её попросит. Чтобы принудительно начать
заново, удалите метаданные:

```bash
rm vision/calibration/geometry.json
python3 -m vision.main
```

В появившемся окне кликайте точки в том порядке, в котором просит программа:

1. углы поля — последовательно по кругу;
2. точки правой стенки;
3. точки левой стенки;
4. две точки линии, по которой ездит каретка.

Не спешите: чем точнее вы укажете реальные границы, тем лучше будет перевод
координат. Клавиша `U` отменяет последнюю ошибочную точку. После успешной
разметки данные сохранятся в `vision/calibration/`.

### 12.3 Настройка цвета мяча

После геометрии откроется окно с ползунками HSV. Белым цветом показывается то,
что программа считает мячом.

1. Положите мяч на обычное место на поле.
2. Меняйте ползунки, пока белым не останется мяч, а фон и блики не исчезнут.
3. Нажмите `Enter`, чтобы сохранить выбранный диапазон в `.env`.
4. Нажмите `Esc`, чтобы отменить изменение.

Если освещение в комнате сильно меняется, проводите калибровку при том же
свете, при котором будет игра. Для метки робота диапазон `ROBOT_HSV_*` пока
задаётся напрямую в `.env` — подберите его тем же принципом.

## 13. Полный запуск игры

Перед запуском должны быть готовы: `.env`, включённое окружение Python,
загруженная прошивка Pico, подключённый Bluetooth-порт и правильная калибровка.

В одном терминале:

```bash
cd /путь/к/wasserschwein
source .venv/bin/activate
sudo rfcomm connect 0 "$(grep '^BT_HC06_MAC=' .env | cut -d= -f2)" 1
```

В другом терминале:

```bash
cd /путь/к/wasserschwein
source .venv/bin/activate
python3 -m vision.main
```

В отладочном окне:

- зелёный круг и линия показывают найденный мяч и его недавние положения;
- синяя линия — рассчитанный будущий путь;
- красная точка — рассчитанная точка встречи;
- в терминале строки `[CMD]` показывают команду, ошибку в миллиметрах и
  желаемую скорость.

Остановить работу можно клавишей `Esc` в окне или `Ctrl+C` в терминале. В обоих
случаях программа пытается отправить `S`, закрыть Bluetooth и освободить камеру.

## 14. Автоматические тесты

Автоматические тесты проверяют небольшие куски логики без камеры, Bluetooth,
Pico и подключения питания. Поэтому их стоит запускать после каждого изменения
кода, но они не заменяют безопасную проверку реального устройства.

### 14.1 Обычный запуск

```bash
source .venv/bin/activate
python3 -m unittest discover -s tests -v
```

Ожидаемый финал:

```text
----------------------------------------------------------------------
Ran ... tests in ...s

OK
```

Сейчас тесты проверяют регулятор каретки:

- **мёртвую зону**: рядом с целью каретка не должна дёргаться;
- **ограничение ускорения**: команда не должна прыгать от нуля к максимуму за
  один кадр;
- **ограничение PWM**: мощность не выходит за безопасный диапазон;
- **аварийный сброс**: после сброса старая команда движения не сохраняется.

Отдельный тест проверяет шаблон `.env.example`: из него должен без ошибок
создаваться заголовок с обязательными настройками Pico. Это защищает от ситуации,
когда в документации есть новая настройка, а в шаблоне её забыли.

### 14.2 Проверка синтаксиса

Эта команда не запускает робота. Она убеждается, что Python может прочитать
файлы как программу:

```bash
PYTHONPYCACHEPREFIX=/tmp/wasserschwein-pycache python3 -m compileall -q vision tools tests
```

Если команда ничего не вывела и вернула вас в приглашение терминала — синтаксис
проверен. Кэш помещается в `/tmp`, поэтому не загрязняет проект.

### 14.3 Проверка `.env` для прошивки

```bash
python3 tools/generate_firmware_env.py --env .env --output /tmp/generated_env.h
```

Это быстрая проверка обязательных параметров `PICO_*`. Она особенно полезна до
долгой сборки на другом компьютере.

## 15. Проверки с настоящим железом

Выполняйте пункты строго по порядку. Следующий этап — только после успешного
предыдущего.

1. **Стоп без движения.** Выполните `python3 -m vision.bluetooth_cli S`. Pico
   должен принять команду без неожиданного движения.
2. **Малая мощность.** На поднятых колёсах отправьте `F 30`, затем `S`. Повторите
   для `B 30`. Проверьте направление и остановку.
3. **Потеря связи.** Дайте небольшую команду движения и оборвите Bluetooth.
   Каретка должна остановиться примерно через `PICO_COMMAND_TIMEOUT_MS`.
4. **Камера и цвета.** Запустите полную программу без мяча. Робот не должен
   ехать. Положите мяч — в окне должен появиться только один зелёный круг.
5. **Потеря мяча.** Во время медленного движения закройте мяч рукой. Не позднее
   `BALL_TIMEOUT_S` программа должна послать `S`.
6. **Потеря метки.** Закройте метку робота. Поведение должно быть таким же:
   остановка, а не движение по последнему положению.
7. **Медленная игра.** Пустите мяч медленно, наблюдая траекторию в окне.
8. **Рабочая скорость.** Только после предыдущих пунктов постепенно поднимайте
   `MOTOR_MAX_PWM`, `CONTROLLER_MAX_SPEED_MM_S` и ускорение.

Запишите результаты каждого теста: дата, значение параметра, направление,
время остановки, замечания. Это намного полезнее, чем менять сразу десять чисел
и пытаться угадать причину.

## 16. Как настраивать поведение робота

### Робот дрожит рядом с точкой

Увеличьте `CONTROLLER_DEADBAND_MM` небольшими шагами, например на 5–10 мм.
Мёртвая зона означает: очень близко к цели мелкая ошибка игнорируется, чтобы
мотор не менял направление каждую долю секунды.

### Робот слишком резко стартует или тормозит

Уменьшите `CONTROLLER_MAX_ACC_MM_S2`. Если он остаётся вялым даже после плавной
настройки, медленно повышайте `CONTROLLER_MAX_SPEED_MM_S`. Всегда начинайте с
низкого `MOTOR_MAX_PWM`.

### Робот не успевает за мячом

Сначала проверьте механику: люфт, ремень, питание, трение, реальную скорость.
Затем увеличивайте по одному `MOTOR_MAX_PWM`, максимальную скорость и ускорение.
Не пытайтесь «исправить» слабый мотор параметрами прогноза мяча.

### Программа видит блики вместо мяча

Сузьте `BALL_HSV_LOWER`/`BALL_HSV_UPPER`, увеличьте `BALL_MIN_AREA_PX` или
`BALL_MIN_CIRCULARITY`. Лучше сначала улучшить освещение и фон: хороший сигнал
всегда надёжнее сложной обработки.

### Программа часто теряет настоящий мяч

Проверьте контраст мяча с полем, фокус камеры и диапазон HSV. Если мяч заметно
изменился в кадре из-за высоты камеры, подстройте `BALL_MIN_RADIUS_PX` и
`BALL_MAX_RADIUS_PX`. Увеличивать `BALL_TIMEOUT_S` стоит осторожно: большой
тайм-аут означает более долгую езду по устаревшим данным.

### Прогноз не похож на настоящий отскок

Сначала повторите калибровку и проверьте размеры поля. Потом сделайте несколько
медленных запусков мяча и настройте `BALL_FRICTION` и `BALL_RESTITUTION` по
одному. `BALL_CURVATURE_K` лучше оставить небольшим или нулевым, пока не ясно,
какое физическое явление он моделирует на вашем поле.

## 17. Что было исправлено и почему

Ниже — не просто список изменений, а причины, почему они важны для реального
робота.

### 17.1 Одни координаты для разметки и игры

**Было.** Поле могло размечаться на одном разрешении, а обработка мяча идти на
другом. Один и тот же номер пикселя тогда означал разные места изображения.

**Риск.** Гомография (карта-переводчик координат) строилась для одной картинки,
а применялась к другой. Робот мог ехать к неверной точке.

**Исправлено.** Камера запрашивается в разрешении из `.env` и оно записывается
в `geometry.json`. Если кадр имеет другой размер, программа не начинает
движение и просит выполнить калибровку заново.

### 17.2 Робот больше не едет по «старому» мячу

**Было.** Сглаживание движения могло продолжать рисовать прогноз после того,
как настоящий мяч пропал из кадра.

**Риск.** Старое положение превращалось в ложную цель, например когда мяч
закрыли рукой или камера на мгновение потеряла изображение.

**Исправлено.** После `BALL_TIMEOUT_S` прогноз сбрасывается, регулятор
обнуляется и посылается `S`. Фильтр Калмана теперь помогает пережить короткий
шум, но не имеет права командовать роботом бесконечно долго без настоящего мяча.

### 17.3 Миллиметры отделены от мощности мотора

**Было.** Одна величина использовалась и как скорость на поле (мм/с), и как PWM
(0–255).

**Риск.** Это разные единицы измерения. Настройка становилась непредсказуемой:
изменение физической скорости могло случайно ломать мощность мотора.

**Исправлено.** Регулятор сначала получает желаемую скорость в мм/с, ограничивает
разгон, а затем переводит результат в PWM в пределах `MOTOR_MAX_PWM`.

### 17.4 Расчёт движения выполняется один раз на кадр

**Было.** Внутреннее состояние регулятора могло обновляться дважды для одного
изображения.

**Риск.** Программа мысленно разгоняла робот быстрее, чем происходило время в
реальном мире. Это приводило к рывкам.

**Исправлено.** На каждом кадре вычисляется реальная разница времени `dt`, а
команда движения рассчитывается один раз.

### 17.5 Отражение мяча от стен

**Было.** Когда расчёт доходил до боковой стены, путь мог оборваться.

**Риск.** В игре мяч обычно отражается, поэтому точка встречи после отскока
получалась неверной.

**Исправлено.** Скорость по горизонтали меняет знак на стене и уменьшается по
коэффициенту `BALL_RESTITUTION` (упругость отскока).

### 17.6 Pico страхует потерю связи

**Было.** При зависшем Python или обрыве Bluetooth последняя команда мотора могла
оставаться активной.

**Риск.** Каретка продолжала движение без компьютера, который её контролирует.

**Исправлено.** В прошивке есть watchdog. Если корректных команд нет дольше
`PICO_COMMAND_TIMEOUT_MS`, каретка останавливается. Пока связь исправна,
компьютер повторяет текущую команду с периодом `COMMAND_RESEND_INTERVAL_S`.

### 17.7 Калибровка ESC не запускается сама

**Было.** Автоматическая калибровка ESC при включении могла происходить рядом с
собранным механизмом.

**Риск.** ESC воспринимает импульсы как команды, а неожиданная последовательность
при старте опасна.

**Исправлено.** По умолчанию в `.env` стоит `PICO_CALIBRATE_ESC_ON_BOOT=0`.
Включайте `1` только для отдельной осознанной процедуры по инструкции ESC, затем
сразу верните `0`, пересоберите и прошейте Pico.

### 17.8 Все настройки собраны в `.env`

**Было.** Параметры были разбросаны по Python, JSON и заголовкам C. Их легко было
забыть изменить в одном месте или случайно сохранить чужие настройки в Git.

**Риск.** Непонятно, какое значение реально работает, а настройка Pico отличалась
от настройки компьютера.

**Исправлено.** `.env` — единственная точка настройки. Python читает его прямо,
а сборка Pico безопасно генерирует временный заголовок из тех же значений.
`.env.example` показывает полный перечень без личных параметров.

### 17.9 Структура проекта стала понятнее

**Было.** Исходники, 3D-модели, скрипты и служебные файлы лежали рядом или в
папках с неочевидными названиями.

**Риск.** Новому человеку трудно понять, что запускать, что прошивать, а что
является моделью корпуса. В Git попадали виртуальные окружения и временные
файлы.

**Исправлено.** Код зрения — в `vision/`, Pico — в `firmware/`, модели — в
`hardware/`, утилиты — в `tools/`, документация — в `docs/`. `.gitignore`
исключает `.venv`, системные файлы и результаты сборки.

## 18. Дополнительные утилиты и YOLO

### Полезные утилиты

| Команда | Назначение |
| --- | --- |
| `python3 tools/camera_index.py` | Ищет доступные номера камер. |
| `python3 tools/hsv_tuner.py` | Открывает отдельный инструмент подбора HSV. |
| `python3 tools/check_gpu.py` | Проверяет GPU для необязательных ML-экспериментов. |
| `python3 -m vision.bluetooth_cli S` | Отправляет единственную безопасную ручную команду стопа. |

### Что такое YOLO и нужен ли он

YOLO — это семейство нейросетей для распознавания объектов на изображении. Ей
нужно много размеченных фотографий, обучение и обычно более мощный компьютер.
Для этого робота она не обязательна: цветовой поиск быстрее настраивается и
проще объясняется. Используйте YOLO, только если простой поиск цвета уже не
справляется с освещением или внешним видом мяча.

Для эксперимента:

```bash
source .venv/bin/activate
python3 -m pip install -r requirements-ml.txt
python3 tools/ml/auto_label.py --help
python3 tools/ml/create_validation_split.py --help
python3 tools/ml/train.py --help
```

Автоматическая разметка — только черновик. Всегда проверьте каждую рамку вокруг
мяча вручную до обучения модели. Docker-файлы в корне относятся к этим
необязательным экспериментам и не нужны для обычной игры.

## 19. Типичные неполадки

| Симптом | Вероятная причина | Что сделать |
| --- | --- | --- |
| `Не найден .env` | Не создан локальный файл настроек. | Выполните `cp .env.example .env`. |
| `No module named cv2` | Не включено или не заполнено `.venv`. | `source .venv/bin/activate`, затем `python3 -m pip install -r requirements.txt`. |
| Камера не открывается | Неверный `CAMERA_ID`, камера занята другой программой. | Запустите `tools/camera_index.py`, закройте другие программы с камерой. |
| Программа просит калибровку | Нет `geometry.json` или разрешение не совпадает. | Проведите разметку заново; не меняйте разрешение после неё. |
| Мяч не находится | Неверный HSV, блики, плохой фокус. | Настройте HSV, освещение и размеры мяча в пикселях. |
| Робот не находится | Неверный цвет метки или её закрывает механизм. | Подберите `ROBOT_HSV_*`, сделайте метку крупнее/контрастнее. |
| `could not open port /dev/rfcomm0` | Bluetooth-порт не создан или указан неверно. | Выполните `rfcomm connect`, проверьте `BT_PORT`. |
| Pico не реагирует | Не совпадают UART-пины или скорость связи. | Сверьте схему, `PICO_PIN_TX/RX`, `BT_BAUDRATE` и `PICO_UART_BAUDRATE`; пересоберите прошивку. |
| Pico не собирается | Не задан/неправилен `PICO_SDK_PATH`. | Проверьте строку в `.env`, затем выполните чистую сборку. |
| Каретка не останавливается | Это аварийная ситуация. | Отключите питание. Затем проверьте `S`, таймер Pico и проводку драйвера до следующего запуска. |
| Команда `make ... deploy` не копирует файл | Другой путь монтирования Pico. | Скопируйте `.uf2` вручную или исправьте `PICO_MOUNT_POINT` в `.env`. |

## 20. Как обновлять проект

Перед обновлением сохраните свой `.env` отдельно: он специально не хранится в
Git. Затем:

```bash
git pull
source .venv/bin/activate
python3 -m pip install -r requirements.txt
```

Сравните свой `.env` с новым `.env.example`: если в шаблоне появились новые
строки, добавьте их в свой файл. После изменений `PICO_*` пересоберите и
перепрошейте Pico. После любых изменений кода запустите тесты:

```bash
python3 -m unittest discover -s tests -v
```

Не добавляйте `.env`, `.venv`, `firmware/build/` и временные калибровочные файлы
в коммит. Они относятся к вашему локальному стенду, а не к исходному коду.

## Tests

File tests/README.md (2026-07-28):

# Автоматические тесты

Эта папка содержит проверки, которые запускаются без камеры, Bluetooth,
Raspberry Pi Pico, моторов и интернета. Они проверяют небольшие части логики и
помогают заметить ошибку до включения настоящего робота.

Запускайте из корня проекта:

```bash
source .venv/bin/activate
python3 -m unittest discover -s tests -v
```

Успешный итог выглядит так:

```text
----------------------------------------------------------------------
Ran ... tests in ...s

OK
```

Сейчас проверяется `vision.robot_controller`:

- рядом с целью действует мёртвая зона: мотор не должен постоянно менять
  направление;
- скорость меняется плавно, с ограничением ускорения;
- мощность PWM не выходит за допустимый диапазон;
- аварийный сброс очищает старую команду движения.

Также проверяется `.env.example`: генератор должен получить из него все
обязательные параметры Pico и создать временный заголовок C.

Эти проверки не заменяют испытание железа. После успешных тестов всё равно
проверьте ручный стоп, малую мощность, потерю Bluetooth и потерю мяча — порядок
описан в [полном руководстве](../docs/PROJECT_GUIDE_RU.md).

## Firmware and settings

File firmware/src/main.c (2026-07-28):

#include <stdio.h>
#include "pico/stdlib.h"
#include "hardware/uart.h"
#include "hardware/pwm.h"
#include "hardware/clocks.h"

#include "arcanoid.h"
#include "constants.h"
#include "uart.h"

uint motor1_slice = 0;
uint motor2_slice = 0;
uint chan1 = 0;
uint chan2 = 0;
uint servo1_slice = 0;
uint servo2_slice = 0;
uint counter = 0;

// Настраивает GPIO, PWM и UART микроконтроллера.
void config(void);
// Выполняет ручную калибровку ESC, если она явно включена в constants.h.
void callibrate_esc(void);
// Запускает ESC толкателя на заранее настроенных безопасных значениях.
void esc_drive(void);
// Останавливает оба ESC толкателя.
void esc_stop(void);

// Инициализирует контроллер и бесконечно обслуживает кнопку, UART и защитный watchdog.
int main(void){
    //IS_DEBUG = true;

    stdio_init_all();
    config();
    sleep_ms(1000);

    printf("RP2040 running!\n");
    esc_stop();
#if CALIBRATE_ESC_ON_BOOT
    callibrate_esc();
#else
    printf("ESC calibration on boot is disabled\n");
#endif

    //cleanup uart buffer
    while(uart_is_readable(uart0)){
        uart_getc(uart0);
    }

    while(true){
        if(button_clicked(BUTTON)){
            // ИНВЕРТИРУЕМ состояние счетчика при каждом клике
            if(counter == 0){
                counter = 1;
                esc_drive();
                gpio_put(LED, 1);
            }else{
                counter = 0;
                esc_stop();
                gpio_put(LED, 0);
            }
        }

        get_uart_buf();
        if(is_cmd_ready){
            parse_uart_buf();
            clear_buf();
        }
        uart_safety_watchdog();
    }

    return 0;
}

// Выполняет последовательность импульсов калибровки ESC только при явном включении флага.
void callibrate_esc(void){
    gpio_put(LED, 1);
    // sleep_ms(500);
    // gpio_put(LED, 0);
    // sleep_ms(500);
    // gpio_put(LED, 1);
    // sleep_ms(500);
    // gpio_put(LED, 0);
    // sleep_ms(500);

    esc_set_speed(MIN_PULSE, SERVO1);
    esc_set_speed(MIN_PULSE, SERVO2);
    sleep_ms(500);
    esc_set_speed(MAX_PULSE, SERVO1);
    esc_set_speed(MAX_PULSE, SERVO2);
    sleep_ms(500);
    esc_set_speed(1100, SERVO1);
    esc_set_speed(1010, SERVO2);
    sleep_ms(500);
    esc_set_speed(MIN_PULSE, SERVO1);
    esc_set_speed(MIN_PULSE, SERVO2);
    gpio_put(LED, 0);
    printf("Callibration pass\n");
}

// Запускает оба ESC толкателя на предварительно проверенных импульсах.
void esc_drive(void){
    gpio_put(LED, 1);
    esc_set_speed(ESC1_TARGET_PULSE, SERVO1);
    esc_set_speed(ESC2_TARGET_PULSE, SERVO2);
}

// Передаёт обоим ESC минимальный импульс, выключающий толкатель.
void esc_stop(void){
    gpio_put(LED, 0);
    esc_set_speed(MIN_PULSE, SERVO1);
    esc_set_speed(MIN_PULSE, SERVO2);
}

// Настраивает выводы Pico для мотора, ESC, UART, светодиода и кнопки.
void config(void){
    gpio_set_function(L, GPIO_FUNC_PWM);
    gpio_set_function(R, GPIO_FUNC_PWM);
    gpio_set_function(SERVO1, GPIO_FUNC_PWM);
    gpio_set_function(SERVO2, GPIO_FUNC_PWM);
    gpio_set_function(TX, GPIO_FUNC_UART);
    gpio_set_function(RX, GPIO_FUNC_UART);
    uart_init(UART_ID, BAUDRATE);
    gpio_init(LED);
    gpio_set_dir(LED, 1);

    motor1_slice = pwm_gpio_to_slice_num(L);
    pwm_set_clkdiv(motor1_slice, MOTOR_DIVIDER);
    pwm_set_wrap(motor1_slice, MOTOR_WRAP);
    pwm_set_enabled(motor1_slice, true);

    motor2_slice = pwm_gpio_to_slice_num(R);
    pwm_set_clkdiv(motor2_slice, MOTOR_DIVIDER);
    pwm_set_wrap(motor2_slice, MOTOR_WRAP);
    pwm_set_enabled(motor2_slice, true);

    servo1_slice = pwm_gpio_to_slice_num(SERVO1);
    pwm_set_clkdiv(servo1_slice, SERVO_DIVIDER);
    pwm_set_wrap(servo1_slice, SERVO_WRAP);
    pwm_set_enabled(servo1_slice, true);

    servo2_slice = pwm_gpio_to_slice_num(SERVO2);
    pwm_set_clkdiv(servo2_slice, SERVO_DIVIDER);
    pwm_set_wrap(servo2_slice, SERVO_WRAP);
    pwm_set_enabled(servo2_slice, true);

    chan1 = pwm_gpio_to_channel(L);
    chan2 = pwm_gpio_to_channel(R);

    pwm_set_chan_level(motor1_slice, chan1, 0);
    pwm_set_chan_level(motor2_slice, chan2, 0);

    gpio_init(BUTTON);
    gpio_set_dir(BUTTON, GPIO_IN);
    gpio_pull_up(BUTTON);
}

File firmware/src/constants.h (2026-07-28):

#ifndef CONSTANTS_H
#define CONSTANTS_H
#include "hardware/clocks.h"
#include "generated_env.h"


//motor constants
#define SYS_FREQ clock_get_hz(clk_sys)
#define MOTOR_WRAP CFG_PICO_MOTOR_WRAP
#define MOTOR_FREQ CFG_PICO_MOTOR_FREQ_HZ
#define MOTOR_DIVIDER (SYS_FREQ / (MOTOR_FREQ * (MOTOR_WRAP + 1)))  // = 48.0
// for trapezoid acceleratoin
#define a_max 1.5
#define m_robot 700 // gramms
#define MAX_VEL CFG_MOTOR_MAX_PWM

//servo init
#define SERVO_WRAP CFG_PICO_SERVO_WRAP
#define SERVO_DIVIDER CFG_PICO_SERVO_DIVIDER
#define MAX_PULSE CFG_PICO_ESC_MAX_PULSE
#define ESC1_TARGET_PULSE CFG_PICO_ESC1_TARGET_PULSE
#define ESC2_TARGET_PULSE CFG_PICO_ESC2_TARGET_PULSE
#define MIN_PULSE CFG_PICO_ESC_MIN_PULSE
#define CALIBRATE_ESC_ON_BOOT CFG_PICO_CALIBRATE_ESC_ON_BOOT

// Защита от зависания компьютера или обрыва Bluetooth: мотор тормозит без новой команды.
#define COMMAND_TIMEOUT_MS CFG_PICO_COMMAND_TIMEOUT_MS

//pins
#define UART_ID uart0
#define BAUDRATE CFG_PICO_UART_BAUDRATE
#define TX CFG_PICO_PIN_TX
#define RX CFG_PICO_PIN_RX
#define LED CFG_PICO_PIN_LED
#define SERVO1 CFG_PICO_PIN_SERVO1
#define SERVO2 CFG_PICO_PIN_SERVO2
#define L CFG_PICO_PIN_MOTOR_LEFT
#define R CFG_PICO_PIN_MOTOR_RIGHT
#define BAT CFG_PICO_PIN_BATTERY
#define BUTTON CFG_PICO_PIN_BUTTON

#endif

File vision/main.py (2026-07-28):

import json
import time
from pathlib import Path

import cv2
import serial

try:
    from .ball_tracker import BallTracker
    from .color_calibrate import ColorCalibrator
    from .config import Config
    from .polygon import PolygonMarker
    from .robot_controller import RobotController
    from .robot_tracker import RobotTracker
except ImportError:
    from ball_tracker import BallTracker
    from color_calibrate import ColorCalibrator
    from config import Config
    from polygon import PolygonMarker
    from robot_controller import RobotController
    from robot_tracker import RobotTracker


BASE_DIR = Path(__file__).resolve().parent
GEOMETRY_FILES = ("perimeter.npy", "left_wall.npy", "right_wall.npy", "robot_beam.npy", "geometry.json")


# Возвращает полный путь к файлу калибровки, чтобы запуск не зависел от текущей папки терминала.
def calibration_path(filename):
    return BASE_DIR / "calibration" / filename


# Настраивает камеру и оставляет единое разрешение для калибровки и рабочего трекинга.
def configure_camera(camera_id, camera_params):
    capture = cv2.VideoCapture(camera_id)
    if not capture.isOpened():
        raise RuntimeError(f"❌ Не удалось открыть камеру {camera_id}")

    capture.set(cv2.CAP_PROP_BUFFERSIZE, 1)
    capture.set(cv2.CAP_PROP_FRAME_WIDTH, int(camera_params["width"]))
    capture.set(cv2.CAP_PROP_FRAME_HEIGHT, int(camera_params["height"]))
    capture.set(cv2.CAP_PROP_FPS, int(camera_params["fps"]))
    for _ in range(5):
        capture.read()
    return capture


# Проверяет, что кадр камеры имеет то же разрешение, в котором была построена гомография.
def geometry_matches_frame(frame):
    metadata_path = calibration_path("geometry.json")
    try:
        with metadata_path.open("r", encoding="utf-8") as metadata_file:
            metadata = json.load(metadata_file)
    except (OSError, json.JSONDecodeError):
        return False

    return (
        metadata.get("frame_width") == frame.shape[1]
        and metadata.get("frame_height") == frame.shape[0]
    )


# Отправляет стоп-команду и возвращает результат записи в Bluetooth-порт.
def send_stop(serial_port):
    if serial_port is None or not serial_port.is_open:
        return False
    try:
        serial_port.write(b"S\n")
        return True
    except serial.SerialException as error:
        print(f"⚠️ Не удалось отправить стоп-команду: {error}")
        return False


# Отправляет одну строковую команду роботу и сообщает, удалось ли записать её в Bluetooth-порт.
def send_command(serial_port, direction, pwm):
    try:
        serial_port.write(f"{direction} {pwm}\n".encode("ascii"))
        return True
    except serial.SerialException as error:
        print(f"⚠️ Ошибка отправки команды: {error}")
        return False


# Запускает калибровку, трекинг и замкнутое управление кареткой робота.
def main():
    config = Config(BASE_DIR.parent / ".env")
    camera_id = config.get_camera_id()
    camera_params = config.get_camera_params()
    bluetooth_params = config.get_bluetooth_params()
    field_params = config.get_field_params()
    geometry_paths = [calibration_path(filename) for filename in GEOMETRY_FILES]

    if not all(path.exists() for path in geometry_paths):
        print("📐 Нет полной калибровки поля. Запускаю разметку.")
        PolygonMarker(
            camera_id,
            frame_size=(camera_params["width"], camera_params["height"]),
            virtual_field_size=(field_params["virtual_width"], field_params["virtual_height"]),
            output_dir=BASE_DIR / "calibration",
        ).run()
        if not all(path.exists() for path in geometry_paths):
            raise RuntimeError("Калибровка не завершена: рабочий запуск отменён ради безопасности")

    calibrator = ColorCalibrator(
        camera_id,
        config=config,
        frame_size=(camera_params["width"], camera_params["height"]),
    )
    color_lower, color_upper = calibrator.calibrate()

    safety_params = config.get_safety_params()
    physics_params = config.get_physics_params()
    ball_tracker_params = config.get_ball_tracker_params()
    tracker = BallTracker(
        calibration_path("perimeter.npy"),
        calibration_path("left_wall.npy"),
        calibration_path("right_wall.npy"),
        calibration_path("robot_beam.npy"),
        detection_timeout_s=safety_params["ball_timeout_s"],
        field_size_mm=(field_params["width_mm"], field_params["height_mm"]),
        virtual_field_size=(field_params["virtual_width"], field_params["virtual_height"]),
        physics_params=physics_params,
        tracker_params=ball_tracker_params,
        color_lower=color_lower,
        color_upper=color_upper,
    )

    controller_params = config.get_controller_params()
    robot_controller = RobotController(
        max_speed_mm_s=controller_params["max_speed_mm_s"],
        max_acc_mm_s2=controller_params["max_acc_mm_s2"],
        max_pwm=controller_params["max_pwm"],
        deadband_mm=controller_params["deadband_mm"],
    )

    capture = None
    serial_port = None
    last_command = None
    last_command_time = 0.0
    last_frame_time = time.monotonic()
    tracking_was_lost = False

    try:
        capture = configure_camera(camera_id, camera_params)
        frame_ok, first_frame = capture.read()
        if not frame_ok:
            raise RuntimeError("❌ Камера не отдала первый кадр")
        if not geometry_matches_frame(first_frame):
            raise RuntimeError(
                "Разрешение камеры отличается от разметки. Удалите geometry.json и выполните калибровку заново."
            )

        serial_port = serial.Serial(bluetooth_params["port"], bluetooth_params["baudrate"], timeout=0.05)
        print(f"✅ Bluetooth подключён: {bluetooth_params['port']} @ {bluetooth_params['baudrate']}")
        robot_lower, robot_upper = config.get_robot_color_bounds()
        robot_tracker = RobotTracker(
            robot_lower,
            robot_upper,
            tracker.M,
            tracker.scale_mm,
            config.get_robot_tracker_params(),
        )
        print("🚀 Система запущена. ESC — безопасная остановка.")

        while True:
            now = time.monotonic()
            dt = min(0.1, max(0.001, now - last_frame_time))
            last_frame_time = now

            frame_ok, frame = capture.read()
            if not frame_ok:
                print("⚠️ Камера перестала отдавать кадры")
                break

            tracker.set_dt(dt)
            target_mm, trajectory_px = tracker.get_prediction(frame, now)
            robot_mm = robot_tracker.get_position(frame)
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

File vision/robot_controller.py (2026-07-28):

import math


class RobotController:
    # Создаёт регулятор положения в физических единицах и параметры перевода в PWM.
    def __init__(
        self,
        max_speed_mm_s,
        max_acc_mm_s2,
        max_pwm,
        deadband_mm,
    ):
        self.max_speed_mm_s = float(max_speed_mm_s)
        self.max_acc_mm_s2 = float(max_acc_mm_s2)
        self.max_pwm = int(max_pwm)
        self.deadband_mm = float(deadband_mm)
        self.current_pos_mm = 0.0
        self.commanded_speed_mm_s = 0.0

    # Сбрасывает внутреннюю командную скорость после аварийной остановки или потери трекинга.
    def reset(self):
        self.commanded_speed_mm_s = 0.0

    # Ограничивает изменение скорости, чтобы команда не требовала мгновенного разгона мотора.
    def _limit_acceleration(self, desired_speed_mm_s, dt):
        max_delta = self.max_acc_mm_s2 * dt
        delta = desired_speed_mm_s - self.commanded_speed_mm_s
        delta = max(-max_delta, min(max_delta, delta))
        self.commanded_speed_mm_s += delta
        return self.commanded_speed_mm_s

    # Переводит требуемую линейную скорость каретки в диапазон PWM контроллера 0…max_pwm.
    def _speed_to_pwm(self, speed_mm_s):
        if self.max_speed_mm_s <= 0:
            return 0
        pwm = round(abs(speed_mm_s) / self.max_speed_mm_s * self.max_pwm)
        return int(max(0, min(self.max_pwm, pwm)))

    # Рассчитывает знаковую скорость и PWM по целевой и измеренной камерой позиции робота.
    def update_motion(self, target_pos_mm, current_pos_mm, dt):
        self.current_pos_mm = float(current_pos_mm)
        dt = max(0.001, min(0.1, float(dt)))
        error_mm = float(target_pos_mm) - self.current_pos_mm

        if abs(error_mm) <= self.deadband_mm:
            self.reset()
            return 0.0, 0

        # Формула гарантирует, что при текущем ускорении остаётся место для торможения.
        braking_limited_speed = math.sqrt(2.0 * self.max_acc_mm_s2 * abs(error_mm))
        desired_speed_mm_s = math.copysign(
            min(self.max_speed_mm_s, braking_limited_speed), error_mm
        )

        commanded_speed_mm_s = self._limit_acceleration(desired_speed_mm_s, dt)
        if abs(commanded_speed_mm_s) < 1e-6:
            commanded_speed_mm_s = 0.0
            self.commanded_speed_mm_s = 0.0

        return commanded_speed_mm_s, self._speed_to_pwm(commanded_speed_mm_s)

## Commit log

2025-08-27 uart for blutooth
2025-09-11 add makefile to assembly project
2025-09-18 workable uart
2025-09-18 add BLDC control
2025-11-13 uart work
2026-01-21 feat uart
2026-01-25 CV 3D
    [GEAR1.FCStd, arcanoid1.3mf.FCStd, arcanoid_new.FCStd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]
2026-03-21 change encoding
    [assembly_pusher.FCStd, back_form_pusher.FCStd, form_pusher.FCStd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]
2026-03-30 change in CV
    [weel_pusher.FCStd, weel_pusher_new.3mf, weel_pusher_new.FCStd]
2026-05-05 unwork tracker
    [ArmTightening.3mf, ArmTightening.FCStd, BLCDGear.3mf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]
2026-05-26 feat cleanup for UART
2026-07-27 Reorganize project and centralize configuration
    [ArmTightening.3mf, ArmTightening.FCStd, BLCDGear.3mf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]
